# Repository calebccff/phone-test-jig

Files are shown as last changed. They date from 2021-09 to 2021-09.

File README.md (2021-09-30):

# OnePlus 6 Test Jig

The OnePlus 6 test jig is a proof of concept designed to turn the OnePlus 6 into a device which can be used in a board farm!

OnePlus 6 Jig 3D view screenshot

The PCB contains a header at the top for soldering wires onto test points on the phone, it features an Atmega32u4 which can act as a
UART<->USB adapter, an LSF0102 bidirectional logic level voltage translator to convert the UART from the 5v of the Atmega down to the
1.8v of the phone (and vice versa).

The Atmega is also used to simulate button presses on the phone, the volume and power button test pads are normally high and pressed when low.
Both of these features can be (though as yet untested) exposed via the same USB port, saving a port on the host and allowing for dirt simple 
control of the device, to test the inputs as well as perform a hard reset.

Being able to hard reset the board is a requirement for consideration in an automated board farm, this carried some complications on the OnePlus 6
as if you perform a hard reset combination (pressing volume up and power at the same time for 10 seconds) whilst VBUS (USB power) is high it will 
boot into EDL mode instead, so without a way to control VBUS the device would just be stuck in EDL. This is resolved by using a high-side FQP27P06
MOSFET.

> **NOTE:** Currently waiting for PCB shipment, expect this design to contain bugs.

## TODO

* Create a list of minimum hard requirements for a given device to be used as part of the farm
* Add a 12v connector and buck regulator to produce VBAT for devices which support it so that the batteries can be removed.
* Add PHONE_USB passthrough port so that devices without USB test points can still have VBUS be controlled by the atmega

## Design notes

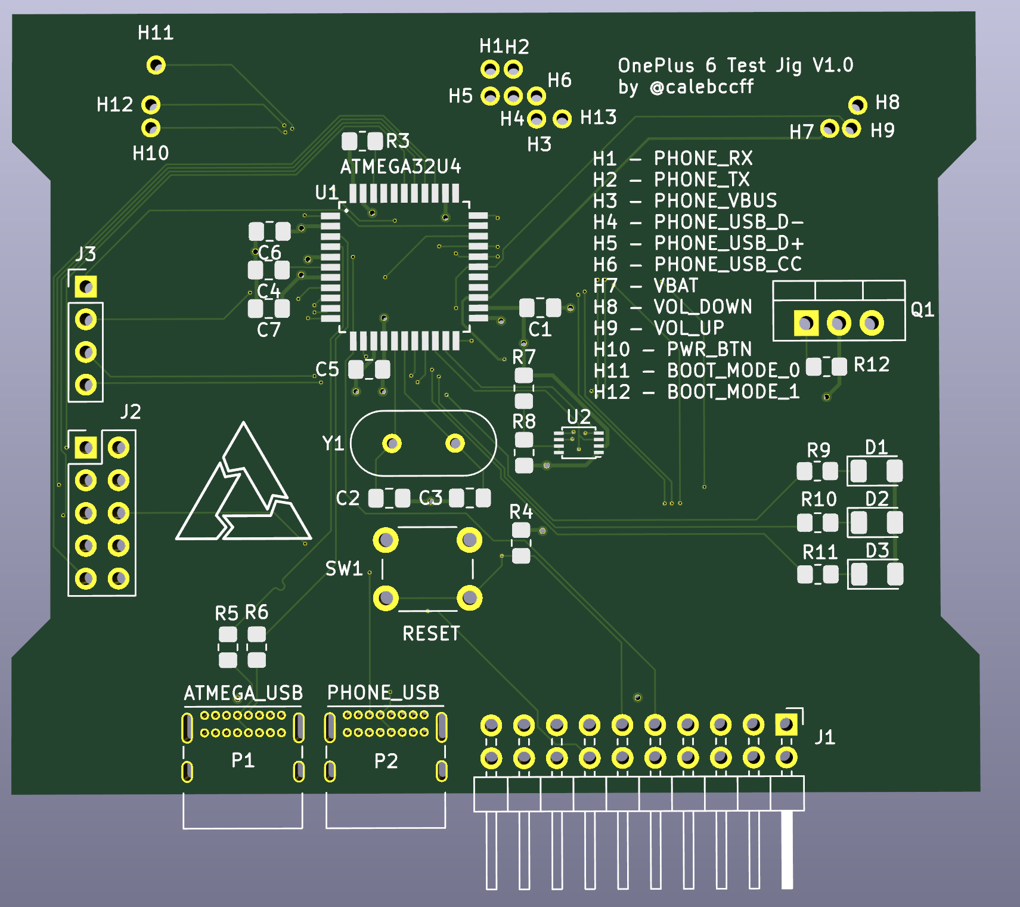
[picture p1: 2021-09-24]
images/pcb-screenshot.png

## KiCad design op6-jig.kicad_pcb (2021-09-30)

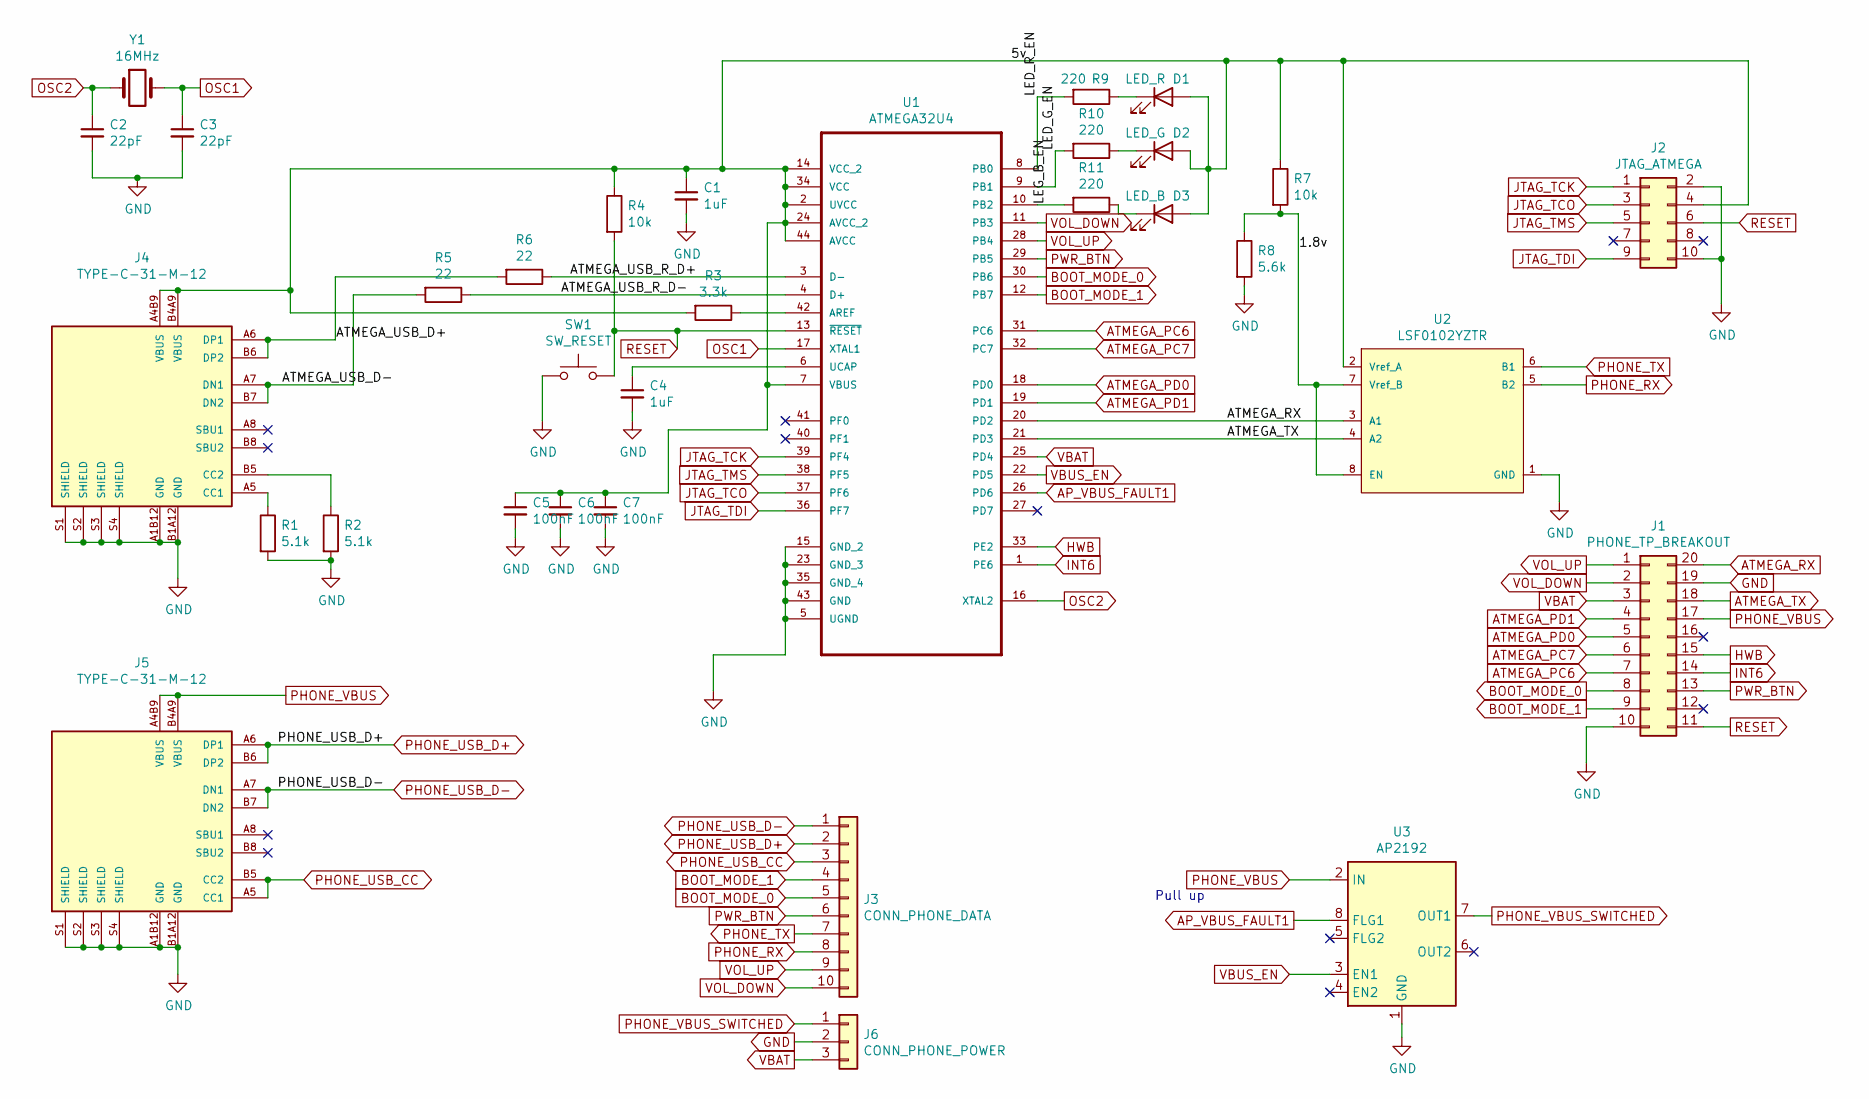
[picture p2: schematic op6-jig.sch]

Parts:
C1, C4: 1uF; C_0805_2012Metric; LCSC C28323
C2, C3: 22pF; C_0805_2012Metric; LCSC C1804
C5, C6, C7: 100nF; C_0805_2012Metric; LCSC C49678
D1: LED_R; LED_1206_3216Metric; LCSC C84256
D2: LED_G; LED_1206_3216Metric; LCSC C2297
D3: LED_B; LED_1206_3216Metric; LCSC C2297
J1: PHONE_TP_BREAKOUT; PinHeader_2x10_P2.54mm_Vertical
J2: JTAG_ATMEGA; PinHeader_2x05_P2.54mm_Vertical
J3: CONN_PHONE_DATA; PinHeader_1x10_P2.54mm_Vertical
J4, J5: TYPE-C-31-M-12; HRO_TYPE-C-31-M-12; LCSC C17414
J6: CONN_PHONE_POWER; PinHeader_1x03_P2.54mm_Vertical
R1, R2: 5.1k; R_0805_2012Metric; LCSC C27834
R3: 3.3k; R_0805_2012Metric; LCSC C26010
R4, R7: 10k; R_0805_2012Metric; LCSC C22859
R5, R6: 22; R_0805_2012Metric; LCSC C17561
R8: 5.6k; R_0805_2012Metric; LCSC C4382
R9, R10, R11: 220; R_0805_2012Metric; LCSC C17557
SW1: SW_RESET; SW_PUSH_6mm
U1: ATMEGA32U4; ATmega32U4
U2: LSF0102YZTR; VSSOP-8_2.4x2.1mm_P0.5mm; mouser part number 595-LSF0102YZTR; digikey description IC LEVEL TRANSLATOR BIDIR 8BGA
U3: AP2192; SO-8_3.9x4.9mm_P1.27mm; LCSC C155322
Y1: 16MHz; Crystal_HC18-U_Vertical

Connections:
/1.8v: R7.2, R8.1, U2.7 (Vref_B), U2.8 (EN)
/5v: C1.1, C5.1, C6.1, C7.1, D1.2 (A), D2.2 (A), D3.2 (A), J2.4, J4.A4B9 (VBUS), J4.B4A9 (VBUS), R3.2, R4.1, R7.1, U1.2 (UVCC), U1.7 (VBUS), U1.14 (VCC_2), U1.24 (AVCC_2), U1.34 (VCC), U1.44 (AVCC), U2.2 (Vref_A)
/ATMEGA_USB_D+: J4.A6 (DP1), J4.B6 (DP2), R6.2
/ATMEGA_USB_D-: J4.A7 (DN1), J4.B7 (DN2), R5.2
/ATMEGA_USB_R_D+: R6.1, U1.3 (D-)
/ATMEGA_USB_R_D-: R5.1, U1.4 (D+)
/LED_G_EN: R10.2, U1.9 (PB1)
/LED_R_EN: R9.2, U1.8 (PB0)
/LEG_B_EN: R11.2, U1.10 (PB2)
AP_VBUS_FAULT1: U1.26 (PD6), U3.8 (FLG1)
ATMEGA_PC6: J1.7, U1.31 (PC6)
ATMEGA_PC7: J1.6, U1.32 (PC7)
ATMEGA_PD0: J1.5, U1.18 (PD0)
ATMEGA_PD1: J1.4, U1.19 (PD1)
ATMEGA_RX: J1.20, U1.20 (PD2), U2.3 (A1)
ATMEGA_TX: J1.18, U1.21 (PD3), U2.4 (A2)
BOOT_MODE_0: J1.8, J3.5, U1.30 (PB6)
BOOT_MODE_1: J1.9, J3.4, U1.12 (PB7)
GND: C1.2, C2.2, C3.2, C4.2, C5.2, C6.2, C7.2, J1.10, J1.19, J2.2, J2.10, J4.A1B12 (GND), J4.B1A12 (GND), J4.S1 (SHIELD), J4.S2 (SHIELD), J4.S3 (SHIELD), J4.S4 (SHIELD), J5.A1B12 (GND), J5.B1A12 (GND), J5.S1 (SHIELD), J5.S2 (SHIELD), J5.S3 (SHIELD), J5.S4 (SHIELD), J6.2, R1.2, R2.2, R8.2, SW1.1, U1.5 (UGND), U1.15 (GND_2), U1.23 (GND_3), U1.35 (GND_4), U1.43 (GND), U2.1 (GND), U3.1 (GND)
HWB: J1.15, U1.33 (PE2)
INT6: J1.14, U1.1 (PE6)
JTAG_TCK: J2.1, U1.39 (PF4)
JTAG_TCO: J2.3, U1.37 (PF6)
JTAG_TDI: J2.9, U1.36 (PF7)
JTAG_TMS: J2.5, U1.38 (PF5)
unnamed: C4.1, U1.6 (UCAP)
unnamed: D1.1 (K), R9.1
unnamed: D2.1 (K), R10.1
unnamed: D3.1 (K), R11.1
unnamed: J4.A5 (CC1), R1.1
unnamed: J4.B5 (CC2), R2.1
unnamed: R3.1, U1.42 (AREF)
OSC1: C3.1, U1.17 (XTAL1), Y1.2
OSC2: C2.1, U1.16 (XTAL2), Y1.1
PHONE_RX: J3.8, U2.5 (B2)
PHONE_TX: J3.7, U2.6 (B1)
PHONE_USB_CC: J3.3, J5.A5 (CC1), J5.B5 (CC2)
PHONE_USB_D+: J3.2, J5.A6 (DP1), J5.B6 (DP2)
PHONE_USB_D-: J3.1, J5.A7 (DN1), J5.B7 (DN2)
PHONE_VBUS: J1.17, J5.A4B9 (VBUS), J5.B4A9 (VBUS), U3.2 (IN)
PHONE_VBUS_SWITCHED: J6.1, U3.7 (OUT1)
PWR_BTN: J1.13, J3.6, U1.29 (PB5)
RESET: J1.11, J2.6, R4.2, SW1.2, U1.13 (~RESET)
VBAT: J1.3, J6.3, U1.25 (PD4)
VBUS_EN: U1.22 (PD5), U3.3 (EN1)
VOL_DOWN: J1.2, J3.10, U1.11 (PB3)
VOL_UP: J1.1, J3.9, U1.28 (PB4)

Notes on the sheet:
Pull up

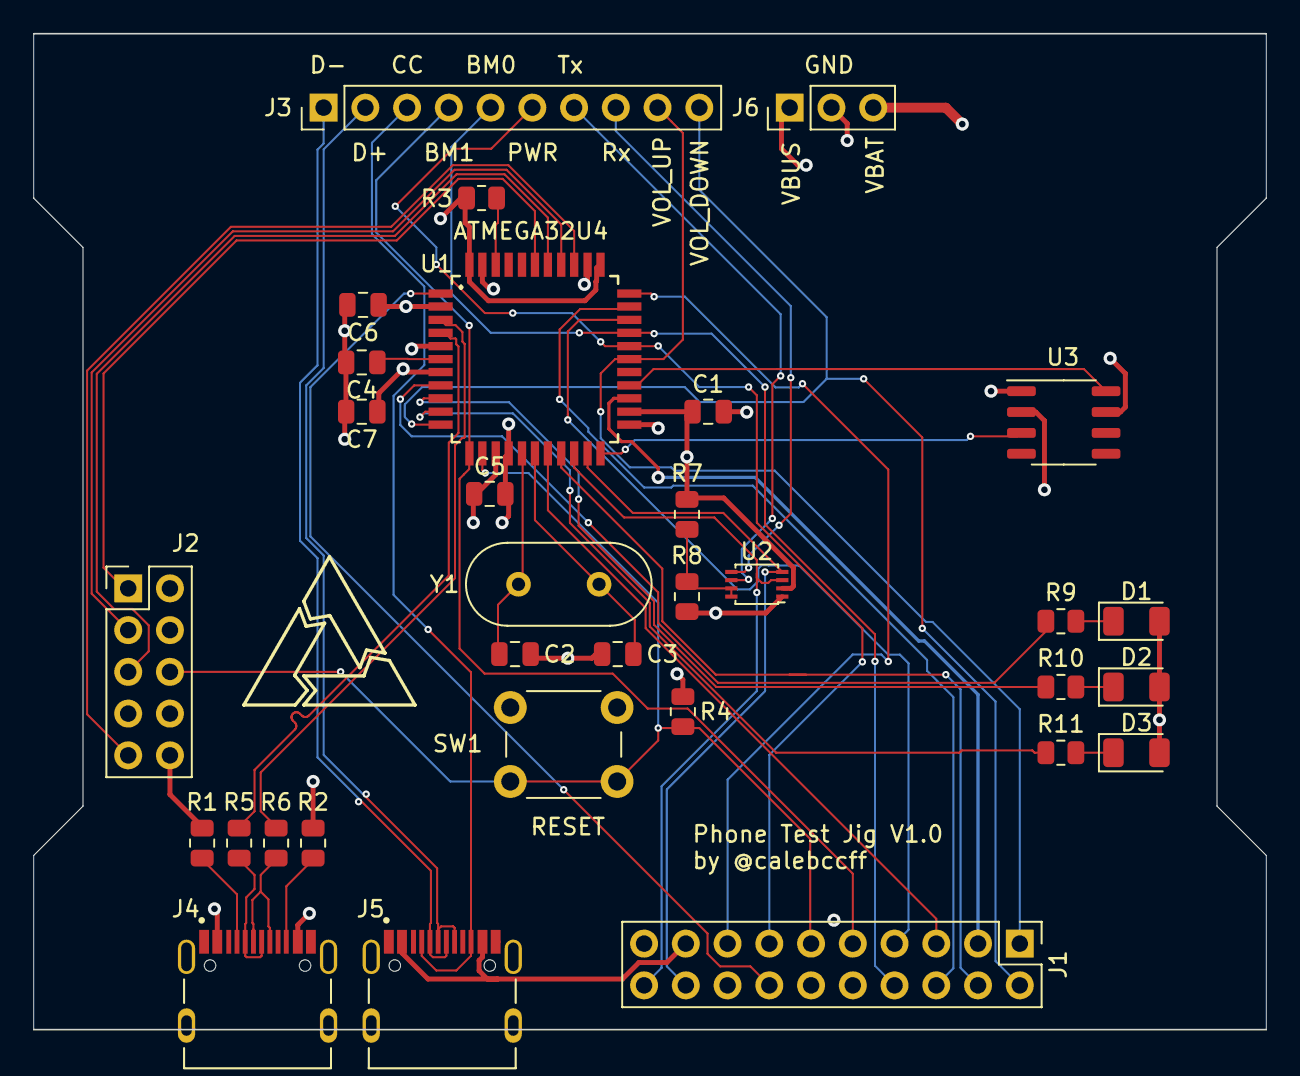
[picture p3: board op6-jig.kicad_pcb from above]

Board: 4 copper layers, 75.0 x 60.6 mm, 32 parts (0 on the bottom side), 47 nets.

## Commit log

2021-08-31 Jig v1.0
    [op6-jig.kicad_pcb, op6-jig.sch]
2021-08-31 PCB: fix missing trace :C
    [op6-jig.kicad_pcb]
2021-09-23 pcb: rewire by hand
    hah, i actually did it...
    The PCB is now hand wired and muuuuuuuch better. This drops the USB pins
    on the breakout header because they probably aren't needed and added too
    much complexity to the traces.
    Also replace the UART pinout with the 5v one on the Atmega side of the
    level shifter rather than the 1.8v levels at the phone.
    * This would mean UART is borked unless you attach 5v to the Atmega USB
    port, maybe we want to power the level shifter with the phone vbus
    supply instead ?
    [op6-jig.kicad_pcb, op6-jig.sch]
2021-09-24 PCB: improve some routing
    Less vias = more good :D
    [op6-jig.kicad_pcb]
2021-09-24 some minor fixes
    [op6-jig.kicad_pcb]
2021-09-27 updates, ready-er to produce?
    * Replaced the mosfet with a switching IC (thanks @A13).
    * Removed ATMEGA MISC header, put those pins on the general 20-pin
    header.
    * Replaced USB-C part with a better SMD part (thanks again @A13).
    * Some misc fixes / routing improvements.
    [op6-jig.kicad_pcb, op6-jig.sch]
2021-09-29 Final-final-v2.docx (it's ordered)
    - Replaced the precisely positioned and probably wrong test points with
    a pin header connector which can just be soldered too.
    - Cleaned up some traces, resized all vias to be a minimum of 0.45mm for
    JLCPCB.
    - Ordered the board!
    [op6-jig.kicad_pcb, op6-jig.sch]
2021-09-30 fix some cap spacing
    [op6-jig.kicad_pcb]
